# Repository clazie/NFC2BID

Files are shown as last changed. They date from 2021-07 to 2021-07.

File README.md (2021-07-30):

# NFC2BID

This project is based on a project from Rainer Kembügler ("onki") from  02. Dezember 2016 
(seen here: `https://onki.de/uebermich/bauberichte/289-bid2nfc-einbau-ins-ladegeraet <https://onki.de/uebermich/bauberichte/289-bid2nfc-einbau-ins-ladegeraet>`_ )

Information can also found here: `https://www.rc-network.de/threads/bid2nfc-als-nachr%C3%BCstl%C3%B6sung.587281/ <https://www.rc-network.de/threads/bid2nfc-als-nachr%C3%BCstl%C3%B6sung.587281/>`_

I collected all informations necessary to build it by my own and refactored the firmware for 
using it with PlatformIO.

# How to build PlatformIO based project

1. `Install PlatformIO Core <http://docs.platformio.org/page/core.html>`_
2. Download `development platform with examples <https://github.com/platformio/platform-atmelavr/archive/develop.zip>`_
3. Extract ZIP archive
4. Run these commands:

.. code-block:: bash

    # Change directory to example
    > cd platform-atmelavr/examples/arduino-blink

    # Build project
    > platformio run

    # Upload firmware
    > platformio run --target upload

    # Build specific environment
    > platformio run -e uno

    # Upload firmware for the specific environment
    > platformio run -e uno --target upload

    # Clean build files
    > platformio run --target clean

# Copyright PlatformIO
    Copyright 2014-present PlatformIO <contact@platformio.org>
    Licensed under the Apache License, Version 2.0 (the "License");
    you may not use this file except in compliance with the License.
    You may obtain a copy of the License at
       http://www.apache.org/licenses/LICENSE-2.0
    Unless required by applicable law or agreed to in writing, software
    distributed under the License is distributed on an "AS IS" BASIS,
    WITHOUT WARRANTIES OR CONDITIONS OF ANY KIND, either express or implied.
    See the License for the specific language governing permissions and
    limitations under the License.

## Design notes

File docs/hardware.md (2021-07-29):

Bei den RFID-RC522 muss man C8 und c8 durch 120pF Kondensatoren ersetzen um eine viel bessere Reichweite zu erreichen.
Wenn man dann unten den Tags noch eine 1,5mm GFK Scheibe legt gehen bei mir die 23mm ONMETALL problemlos.

## MFRC-522
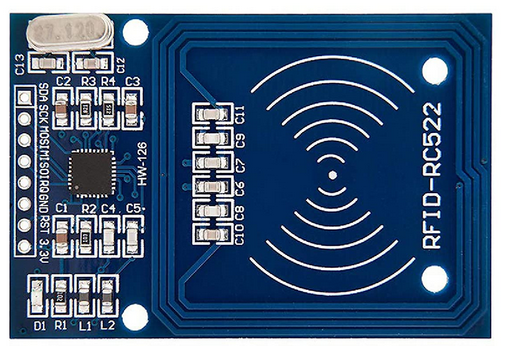
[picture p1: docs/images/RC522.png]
MFRC-522


Dieses RFID-Modul erlaubt das Auslesen und Beschreiben von RFID-Tags und ist sowohl für Einplatinen-Computer wie Raspberry Pi als auch für Einplatinen-Mikrocontroller wie Arduino einsetzbar.

• RFID-Modul mit integrierten NXP MFRC-522
• 13,56 MHz Frequenz
• Kommunikation über SPI
• basierend auf dem Mifare Protokoll
• erlaubt das Auslesen und Beschreiben von RFID-Tags

### RFID-Tags
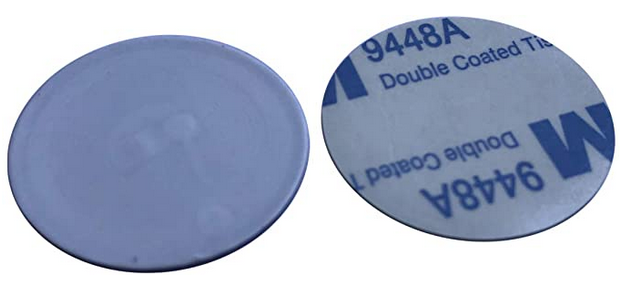
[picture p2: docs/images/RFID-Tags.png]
RFID-Tags


NFC Aufkleber RFID anti-metal auf Metall Tag Label MIFARE Classic® 1K 13,56MHz Dia 25mm

The tag is a Mifare transponder with 1 KB of memory which is divided into 16 sectors, each sector into 4 blocks and each block can store 2 bytes of data. Each sector has two keys (A/B) which can be assigned with rights for reading and writing memory blocks. The last block contains the keys and the rights (access conditions).

The sectors are numbered from 0 to 15 and the block number for every block (containing 2 bytes) is serially numbered from 0 to 63.

The Mifare classic has a proprietary “Crypto-1” algorithm which is not secure anymore since 2008. There are newer MIFARE DESFire EV1 and EV2 tags which are secure until today. But for some DIY projects the security is in my case not so important.

# Arduino Pro Mini 3,3V, 8MHz

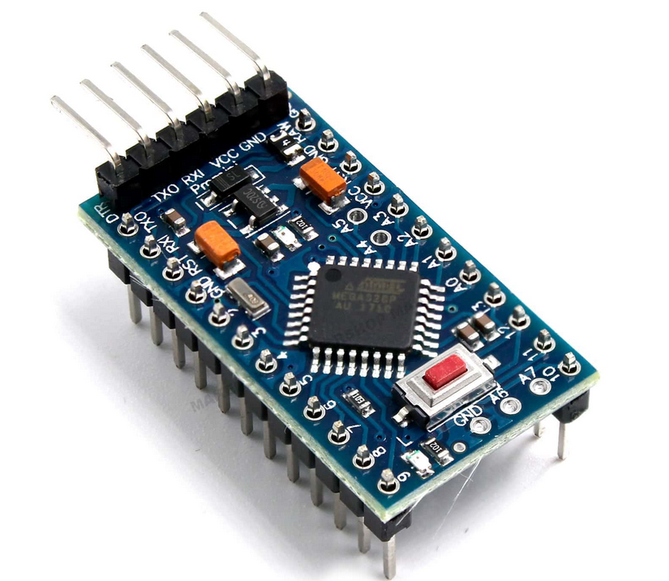
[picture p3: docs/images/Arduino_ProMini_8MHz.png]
Arduino Pro Mini 3,3V, 8MHz


# Verdrahtung
## RC522
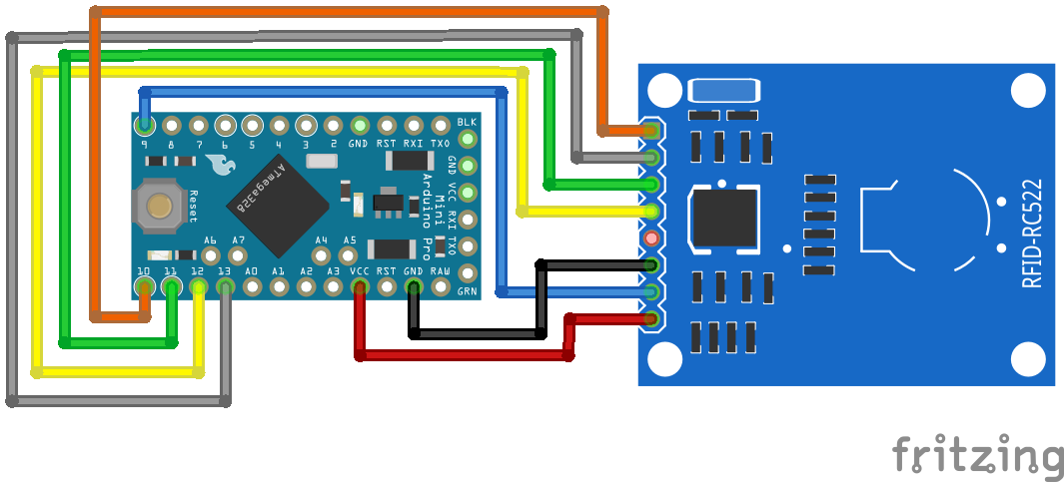
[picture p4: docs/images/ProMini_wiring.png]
Verdrahtung


| RC522 RFID Reader | Arduino Nano, Pro Mini 3.3V, Uno |
|---|---|
| SDA | 10 |
| SCK | 13 |
| MOSI | 11 |
| MISO | 12 |
| IRQ | not connected |
| GND | GND |
| RST | 9 |
| 3.3V | 3V3 |

## BID
| Signal | BID | ProMini  |
|---|---|---|
| GND | Black | GND |
| SCK | Green | A4 |
| SCL | White | A5 |
| VCC | Orange| not conn.|

## LED

| Signal | LED | ProMini |
|---|---|---|
| GND | K | GND |
| LED | A (330 Ohm) | A1 |

# Links
* [https://diyi0t.com/rfid-sensor-tutorial-for-arduino-and-esp8266/](https://diyi0t.com/rfid-sensor-tutorial-for-arduino-and-esp8266/)
* [https://onki.de/uebermich/bauberichte/288-bid2nfc-drahtlos-bid-chip-fuer-robbe-lader](https://onki.de/uebermich/bauberichte/288-bid2nfc-drahtlos-bid-chip-fuer-robbe-lader)
* [https://onki.de/uebermich/bauberichte/289-bid2nfc-einbau-ins-ladegeraet](https://onki.de/uebermich/bauberichte/289-bid2nfc-einbau-ins-ladegeraet)

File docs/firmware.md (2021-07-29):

## Links 
* [https://www.rc-network.de/threads/bid2nfc-als-nachr%C3%BCstl%C3%B6sung.587281/page-4](https://www.rc-network.de/threads/bid2nfc-als-nachr%C3%BCstl%C3%B6sung.587281/page-4)
* [https://www.rc-network.de/threads/bid2nfc-bid-kabellos-am-ladeger%C3%A4t-nutzen.11779777/](https://www.rc-network.de/threads/bid2nfc-bid-kabellos-am-ladeger%C3%A4t-nutzen.11779777/)
* [https://www.rc-thoughts.com/](https://www.rc-thoughts.com/)
* [https://apollo.open-resource.org/mission:log:2012:10:06:free-and-open-source-junsi-icharger-data-logger](https://apollo.open-resource.org/mission:log:2012:10:06:free-and-open-source-junsi-icharger-data-logger)
* [https://www.jetiforum.de/index.php/23-fremdprodukte/5653-arduino-library-fuer-jeti-ex-eigenbau-telemetrie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](https://www.jetiforum.de/index.php/23-fremdprodukte/5653-arduino-library-fuer-jeti-ex-eigenbau-telemetrie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)
* [https://sourceforge.net/projects/jetiexsensorcpplib/](https://sourceforge.net/projects/jetiexsensorcpplib/)
* [https://github.com/openXsensor/openXsensor/wiki](https://github.com/openXsensor/openXsensor/wiki)
* [https://maskaravivek.medium.com/understanding-the-format-of-ndef-messages-part-1-44ec179a5f45](https://maskaravivek.medium.com/understanding-the-format-of-ndef-messages-part-1-44ec179a5f45)
*  [https://github.com/Sepp62/JetiExBus](https://github.com/Sepp62/JetiExBus)

# Ausgaben auf der seriellen

```
V1.0.0
Scan a MIFARE Classic card
Chip gefunden!     
Lese Seriennummer aus :block was read
EB74496EB88402C778ABB477F81D
Start lesenblock was read
block was read
block was read
block was read
block was read
block was read
block was read
block was read
block was read
block was read
block was read
block was read
block was read
block was read
block was read
block was read
ende lesen    
Print BID Data
00: 02 97 00 04 00 04 00 00 00 00 00 00 00 00 00 00
10: 00 00 00 00 00 00 00 00 00 00 00 00 00 00 00 00
20: 00 00 00 00 00 00 00 00 00 00 00 00 00 00 00 00
30: 00 00 00 00 00 00 00 00 00 00 00 00 00 00 00 00
40: 0f 04 10 02 03 13 88 27 10 13 88 0b b8 00 37 00
50: 00 00 00 00 00 00 00 00 00 00 00 00 00 00 00 00
60: 00 00 00 00 00 00 00 00 00 00 00 00 00 00 00 00
70: 00 00 00 00 00 00 00 00 00 00 00 00 00 00 00 00
80: 02 97 00 04 00 04 00 00 00 00 00 00 00 00 00 00
90: 00 00 00 00 00 00 00 00 00 00 00 00 00 00 00 00
a0: 00 00 00 00 00 00 00 00 00 00 00 00 00 00 00 00
b0: 00 00 00 00 00 00 00 00 00 00 00 00 00 00 00 00
c0: 0f 04 10 02 03 13 88 27 10 13 88 0b b8 00 37 00
d0: 00 00 00 00 00 00 00 00 00 00 00 00 00 00 00 00
e0: 00 00 00 00 00 00 00 00 00 00 00 00 00 00 00 00
f0: 00 00 00 00 00 00 00 00 00 00 00 00 00 00 00 00
Checksum:       663
act_charge:     4
max_charged:    4
chg_cycles:     0
year:           15
month:          4
day:            16
acctyp:         2
cells:          3
capacity:       5000
chg_current:    10000
dischg_current: 5000
dischg_limit:   3000
d_peak:         0
cut_temp:       55
unknown:        0
unknown_8[0]:   0
unknown_8[1]:   0
unknown_8[2]:   0
unknown_8[3]:   0
unknown_8[4]:   0
unknown_8[5]:   0
unknown_8[6]:   0
unknown_8[7]:   0
read errors:
0
```

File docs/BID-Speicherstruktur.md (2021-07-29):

## Struktur

```c
#pragma pack(push, 1)
typedef struct {
  endian16  checksum;         // [0..1]  Checksum, sum up bytes from 2..127
  endian16  act_charge;       // [2..3]
  endian16  max_charged;      // [4..5]
  endian16  chg_cycles;       // [6..7]
  uint8_t   unknown_8[63-7];  // [8..63]
  uint8_t   year;             // [64]
  uint8_t   month;            // [65]
  uint8_t   day;              // [66]
  uint8_t   acctyp;           // [67]
  uint8_t   cells;            // [68]
  endian16  capacity;         // [69..70]
  endian16  chg_current;      // [71..72]
  endian16  dischg_current;   // [73..74]
  endian16  dischg_limit;     // [75..76] discharge limit in mv/Cell
  uint8_t   d_peak;           // [77] delta peak value
  uint8_t   cut_temp;         // [78] cut off temperature
  uint8_t   unknown;
  uint8_t   unknown75[128-80];
}tBID_data;
#pragma pack(pop)
```
Infos gibt|s hier[https://www.rc-network.de/threads/bid-bzw-ams-mit-pc-auslesen486956/](https://www.rc-network.de/threads/bid-bzw-ams-mit-pc-auslesen.486956/) und hier:[https://rchelifan.org/viewtopic.php?f=63&t=59994&hilit=BID+Chip](https://rchelifan.org/viewtopic.php?f=63&t=59994&hilit=BID+Chip).

* Checksumme
* Akkutyp
* Zellenzahl
* Akkukapazität
* Ladestrom
* Entladestrom
* Akkudatum (Tag, Monat, Jahr)
* Anzahl Zyklen
* geladene Kapazität (letzter Ladevorgang)
* entladene Kapazität (letzter Entladevorgang)
* geladene Kapazität (Maximalwert)
* entladene Kapazität (Maximalwert)

Zur Speicherorganisation: Es stehen insgesamt 256 Byte zur Verfügung (8 x 256 Byte = 2 kBit)
Die Daten werden vom Byte 0 bis 127 geschrieben und anschließend ein zweites Mal von Byte 128 bis 255,
also eine 1:1 Spiegelung. Für die obengenannten Daten werden derzeit 23 Bytes genutzt (gespiegelt also 46 Byte von 256 zur Verfügung stehenden Bytes).

+----------------+
|J1     +-+ C1   |
|--+    +-+      |
|  |1   8 7 6 5  |
|  |2   +-----+  |
|  |3   ) IC1 |  |
|  |4   +-----+  |
|--+    1 2 3 4  |
+----------------+

J1:
1 ... or --> VCC --> Arduino 5V
2 ... ws --> SCL --> Arduino Pin 5
3 ... gn --> SDA --> Arduino Pin 4
4 ... sw --> GND --> Arduino GND

IC1: A21SC (=> 24C02 ?)
1 ... E0  --> GND
2 ... E1  --> GND
3 ... E2  --> GND
4 ... GND --> J1-4
5 ... SDA --> J1-3
6 ... SCL --> J1-2
7 ... /WC --> GND  --> C1-1
8 ... VCC --> J1-1 --> C1-2

```c++
#include <Wire.h>

#define BID_ADDRESS (0xA << 3 | 0x0)

int bid_year, bid_month, bid_day;
int bid_cells, bid_acctyp, bid_cap_h, bid_cap_l, bid_chcurr_h, bid_chcurr_l, bid_dchcurr_h, bid_dchcurr_l;
int bid_actc_h, bid_actc_l, bid_actdc_h, bid_actdc_l, bid_maxc_h, bid_maxc_l;
int bid_chcnt_h, bid_chcnt_l;

// EEPROM Routine from http://www.arduino.cc/playground/Code/I2CEEPROM
// adopted to read EEPROMS with 1 Byte address
byte i2c_eeprom_read_byte( int deviceaddress, byte eeaddress ) {
  byte rdata = 0xFF;
  Wire.beginTransmission(deviceaddress);
//  Wire.send((int)(eeaddress >> 8)); // MSB
//  Wire.send((int)(eeaddress & 0xFF)); // LSB
  Wire.send((int)(eeaddress)); 
  Wire.endTransmission();
  Wire.requestFrom(deviceaddress,1);
  if (Wire.available()) rdata = Wire.receive();
  return rdata;
}

void setup() {
  // ...
  Wire.begin();   // start Wire library as I2C-Bus Master
  Serial.begin(9600); // 
  
    int i;
    byte bid_data;
    
    Serial.print("BID-Adresse: ");
    Serial.println(BID_ADDRESS, HEX);    
    
  Serial.println("Start EEPROM_READ");
for (i = 0; i <= 255; i++){
    Serial.print(i, DEC);
    Serial.print(": ");
    bid_data = i2c_eeprom_read_byte( BID_ADDRESS, i );
    Serial.println(bid_data, HEX); 
      switch (i) {
    case 2:
      //Actual Chaged Capacity (mAh) High Byte
      bid_actc_h = bid_data;
      break;
    case 3:
      //Actual Chaged Capacity (mAh) Low Byte
      bid_actc_l = bid_data;
      break;
    case 4:
      //Maximum Chaged Capacity (mAh) High Byte
      bid_maxc_h = bid_data;
      break;
    case 5:
      //Maxiimum Chaged Capacity (mAh) Low Byte
      bid_maxc_l = bid_data;
      break;
    case 6:
      //Charging Cycles High Byte
      bid_chcnt_h = bid_data;
      break;
    case 7:
      //Charging Cycles Low Byte
      bid_chcnt_l = bid_data;
      break;

    case 64:
      //Year
      bid_year = bid_data;
      break;
    case 65:
      //Month
      bid_month = bid_data;
      break;
    case 66:
      //Day
      bid_day = bid_data;
      break;
    case 67:
      //Accu Type
      bid_acctyp = bid_data;
      break;
    case 68:
      //Cells
      bid_cells = bid_data;
      break;
    case 69:
      //Capacaity(mAh) High Byte
      bid_cap_h = bid_data;
      break;
    case 70:
      //Capacaity(mAh) Low Byte
      bid_cap_l = bid_data;
      break;
    case 71:
      //Charg. Current(mA) High Byte
      bid_chcurr_h = bid_data;
      break;
    case 72:
      //Charg. Current(mA) Low Byte
      bid_chcurr_l = bid_data;
      break;
    case 73:
      //Discharg. Current(mA) High Byte
      bid_dchcurr_h = bid_data;
      break;
    case 74:
      //Discharg. Current(mA) Low Byte
      bid_dchcurr_l = bid_data;
      break;
  }

    delay(5);
}
  Serial.println("End EEPROM_READ");

Serial.println("BID Daten:");
Serial.print("Datum: ");
Serial.print(bid_day);
Serial.print(".");
Serial.print(bid_month);
Serial.print(".");
Serial.print(2000 + bid_year);
Serial.println("");

Serial.print("Akku-Typ: ");
      switch (bid_acctyp) {
        case 0:
          Serial.print("NiCd");
          break;
        case 1:
          Serial.print("NiMH");
          break;
        case 2:
          Serial.print("LiPo");
          break;
        default:
          Serial.print(bid_acctyp);
          Serial.print("?");
          break;
      }
Serial.println("");

Serial.print("Zellenzahl: ");
Serial.print(bid_cells);
Serial.print(" -> ");
      switch (bid_acctyp) {
        case 0:
          Serial.print(1.2 * bid_cells);
          break;
        case 1:
          Serial.print(1.2 * bid_cells);
          break;
        case 2:
          Serial.print(3.7 * bid_cells);
          break;
      }
Serial.print(" V");
Serial.println("");

Serial.print("Kapazitaet: ");
Serial.print(bid_cap_h * 256 + bid_cap_l);
Serial.print(" mAh");
Serial.println("");

Serial.print("Ladestrom: ");
Serial.print(bid_chcurr_h * 256 + bid_chcurr_l);
Serial.print(" mA");
Serial.println("");

Serial.print("Entladestrom: ");
Serial.print(bid_dchcurr_h * 256 + bid_dchcurr_l);
Serial.print(" mA");
Serial.println("");

Serial.print("akt. Lad.: ");
Serial.print(bid_actc_h * 256 + bid_actc_l);
Serial.print(" mAh");
Serial.println("");

Serial.print("max. Lad.: ");
Serial.print(bid_maxc_h * 256 + bid_maxc_l);
Serial.print(" mAh");
Serial.println("");

Serial.print("Ladezyklen: ");
Serial.print(bid_chcnt_h * 256 + bid_chcnt_l);
Serial.println("");

  // ...
}

void loop() {
  // ...
  // ...
}

```

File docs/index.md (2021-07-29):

# NFC2BID

Diese Dokumentation wurde mit MkDocs erstellt. Bitte bei Änderungen nicht die Html-Seiten auf dem Webserver ändern, sondern die **"*.md"** Datei im Unterverzeichnis **"docs"** der Quelldateien ändern.

Die Quelldateien befinden sich im Verzeichnis **docs** des Repositorys
## Serve
Mit dem Kommando 
```sh
mkdocs serve
```
wird ein Webserver gestartet und die erzeugten Doc-Html Dateien können mit dem Webbrowser unter der Adresse [`http://localhost:8000/`](http://localhost:8000/) aufgerufen werden. Jede Änderung wird im Webbrowser direkt sichtbar. Mit `Ctrl-C` wird der Webserver beendet.

## Build
Mit dem Kommando 
```sh
mkdocs build
```
werden die Html-Dateien erzeugt und in das Webserver Verzeichnis `\\raspidbsrv\web\html\doku\nfc2bid` kopiert und kann dann im Webbrowser unter der Adresse [`https://192.168.15.107/doku/nfc2bid/`](https://192.168.15.107/doku/nfc2bid/) aufgerufen werden.

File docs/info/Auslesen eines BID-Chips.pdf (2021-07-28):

Auslesen eines BID-Chips mit Arduino. Verwendetes EEPROM: 24LC02 (256x8 Bit)

BID-Adresse (DEC): 80

Start EEPROM_READ

Byte: Inhalt

(DEC) (HEX)

0: | 2A
1: | 4
2: | 0
3: | 0
4: | 0
5: | 0
6: | 0
7: | 0
8: | 6
9: | 28
10: | 6
11: | 28
12: | 0
13: | 0
14: | 0
15: | 0
16: | 0
17: | 0
18: | 0
19: | 0
20: | 0
21: | 0

22: | 0
23: | 0
24: | 0
25: | 0
26: | 0
27: | 0
28: | 0
29: | 0
30: | 0
31: | 0
32: | 0
33: | 0
34: | 0
35: | 0
36: | 0
37: | 0
38: | 0
39: | 0
40: | 0
41: | 0
42: | 0
43: | 0
44: | 0
45: | 0
46: | 0
47: | 0
48: | 0
49: | 0

50: | 0
51: | 0
52: | 0
53: | 0
54: | 0
55: | 0
56: | 0
57: | 0
58: | 0
59: | 0
60: | 0
61: | 0
62: | 0
63: | 0
64: | 11
65: | 3
66: | 3
67: | 2
68: | 6
69: | 13
70: | 88
71: | 1F
72: | A4
73: | 13
74: | 88
75: | C
76: | 80
77: | 4

78: | 0
79: | 0
80: | 0
81: | 0
82: | 0
83: | 0
84: | 0
85: | 0
86: | 0
87: | 0
88: | 0
89: | 0
90: | 0
91: | 0
92: | 0
93: | 0
94: | 0
95: | 0
96: | 0
97: | 0
98: | 0
99: | 0
100: | 0
101: | 0
102: | 0
103: | 0
104: | 0
105: | 0

106: | 0
107: | 0
108: | 0
109: | 0
110: | 0
111: | 0
112: | 0
113: | 0
114: | 0
115: | 0
116: | 0
117: | 0
118: | 0
119: | 0
120: | 0
121: | 0
122: | 0
123: | 0
124: | 0
125: | 0
126: | 0
127: | 0
128: | 3
129: | 4
130: | 0
131: | 0
132: | 0
133: | 0

134: | 0
135: | 0
136: | 6
137: | 28
138: | 6
139: | 28
140: | 0
141: | 0
142: | 0
143: | 0
144: | 0
145: | 0
146: | 0
147: | 0
148: | 0
149: | 0
150: | 0
151: | 0
152: | 0
153: | 0
154: | 0
155: | 0
156: | 0
157: | 0
158: | 0
159: | 0
160: | 0
161: | 0

162: | 0
163: | 0
164: | 0
165: | 0
166: | 0
167: | 0
168: | 0
169: | 0
170: | 0
171: | 0
172: | 0
173: | 0
174: | 0
175: | 0
176: | 0
177: | 0
178: | 0
179: | 0
180: | 0
181: | 0
182: | 0
183: | 0
184: | 0
185: | 0
186: | 0
187: | 0
188: | 0
189: | 0

190: | 0
191: | 0
192: | 11
193: | 3
194: | 3
195: | 2
196: | 6
197: | 13
198: | 88
199: | 1F
200: | A4
201: | 13
202: | 88
203: | C
204: | 80
205: | 4
206: | 0
207: | 0
208: | 0
209: | 0
210: | 0
211: | 0
212: | 0
213: | 0
214: | 0
215: | 0
216: | 0
217: | 0

218: | 0
219: | 0
220: | 0
221: | 0
222: | 0
223: | 0
224: | 0
225: | 0
226: | 0
227: | 0
228: | 0
229: | 0
230: | 0
231: | 0
232: | 0
233: | 0
234: | 0
235: | 0
236: | 0
237: | 0
238: | 0
239: | 0
240: | 0
241: | 0
242: | 0
243: | 0
244: | 0
245: | 0

246: | 0
247: | 0
248: | 0
249: | 0
250: | 0
251: | 0
252: | 0
253: | 0
254: | 0
255: | 0

End EEPROM_READ

BID Daten:

Datum: 3.3.2017

Akku-Typ: LiPo

Zellenzahl: 6 -> 22.20 V

Kapazitaet: 5000 mAh

Ladestrom: 8100 mA

Entladestrom: 5000 mA

akt. Lad.: 0 mAh

max. Lad.: 0 mAh

Ladezyklen: 0

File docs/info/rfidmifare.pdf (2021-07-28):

## Using a MFRC522 reader to read and write MIFARE RFID cards

on ARDUINO through the MFRC522 library BY COOQROBOT.
Mario Capurso (m.capurso@libero.it)

MIFARE is the NXP Semiconductors-owned trademark of a series of chips widely
used in contactless smart cards and proximity cards. According to the producers, billions of smart card chips and many millions of reader modules have been sold. [1]

The technology is owned by NXP Semiconductors (spin off from Philips Electronics in 2006) with headquarters in Eindhoven, Netherlands, and main business sites in Nijmegen, Netherlands, and Hamburg, Germany.

The MIFARE name covers proprietary technologies based upon various levels of the ISO/IEC 14443 Type A 13.56 MHz contactless smart card standard.
The MIFARE name (derived from the term MIkron FARE Collection System) covers
seven different kinds of contactless cards.

MIFARE Classic employs a proprietary protocol compliant to parts (but not all) of ISO/IEC 14443-3 Type A, with an NXP proprietary security protocol for authentication and ciphering.

The MIFARE Classic card is fundamentally just a memory storage device, where the memory is divided into segments and blocks with simple security mechanisms for access control. They are ASIC-based and have limited computational power. Thanks
to their reliability and low cost, those cards are widely used for electronic wallet, access control, corporate ID cards, transportation or stadium ticketing.

The MIFARE Classic 1K offers 1024 bytes of data storage, split into 16 sectors; each sector is protected by two different keys, called A and B. Each key can be programmed to allow operations such as reading, writing, increasing valueblocks, etc. MIFARE Classic 4K offers 4096 bytes split into forty sectors, of which 32 are same size as in the 1K with eight more that are quadruple size sectors. MIFARE Classic mini offers 320 bytes split into five sectors.

For each of these card types, 16 bytes per sector are reserved for the keys and access conditions and can not normally be used for user data. Also, the very first 16 bytes contain the serial number of the card and certain other manufacturer data and are read only. That brings the net storage capacity of these cards down to 752 bytes for MIFARE Classic 1k, 3440 bytes for MIFARE Classic 4k, and 224 bytes for Mini. It uses an NXP proprietary security protocol (Crypto-1) for authentication and ciphering.

The encryption used by the MIFARE Classic card uses a 48 bit key. [18]
A presentation by Henryk Plötz and Karsten Nohl[19] at the Chaos Communication Congress in December 2007 described a partial reverse-engineering of the algorithm used in the MIFARE Classic chip. Abstract and slides[20] are available online. A paper that describes the process of reverse engineering this chip was published at the August 2008 USENIX security conference.[21] (https://www.usenix.org/legacy/events/sec08/tech/full_papers/nohl/nohl.pdf)

In March 2008 the Digital Security[22] research group of the Radboud University Nijmegen made public that they performed a complete reverse-engineering and
were able to clone and manipulate the contents of an OV-Chipkaart which is a MIFARE Classic card.[23] (http://www.cs.ru.nl/~flaviog/publications/Talk.Mifare.pdf) For demonstration they used the Proxmark device, a 125 kHz / 13.56 MHz research instrument.[24] The schematics and software are released under the free GNU General Public License by Jonathan Westhues in 2007. They demonstrate it is even possible to perform card-only attacks using just an ordinary stock-commercial NFC reader in combination with the libnfc library.

In April 2009 new and better card-only attack on MIFARE Classic has been
found. It was first announced at the Rump session of Eurocrypt 2009.[35] This attack was presented at SECRYPT 2009.[36] The full description of this latest and fastest attack to date can also be found in the IACR preprint archive.[37] The new attack improves by a factor of more than 10 all previous card-only attacks on MIFARE Classic, has instant running time, and it does not require a costly precomputation.

The new attack allows to recover the secret key of any sector of MIFARE Classic card via wireless interaction, within about 300 queries to the card. It can then be combined with the nested authentication attack in the Nijmegen Oakland paper to recover subsequent keys almost instantly. Both attacks combined and with the right hardware equipment such as Proxmark3, one should be able to clone any MIFARE Classic card in not more than 10 seconds. This is much faster than previously thought.

The MFRC522 is a highly integrated reader/writer IC for contactless communication at 13.56 MHz. The MFRC522 reader supports ISO/IEC 14443 A/MIFARE mode.
The MFRC522’s internal transmitter is able to drive a reader/writer antenna designed to communicate with ISO/IEC 14443 A/MIFARE cards and transponders without additional active circuitry. The receiver module provides a robust and efficient implementation for demodulating and decoding signals from ISO/IEC 14443 A/MIFARE compatible cards and transponders. The digital module manages the complete ISO/IEC 14443 A framing and error detection (parity and CRC) functionality.

The MFRC522 supports all variants of the MIFARE Mini, MIFARE 1K, MIFARE 4K, MIFARE Ultralight, MIFARE DESFire EV1 and MIFARE Plus RF identification protocols. To aid readability throughout this data sheet, the MIFARE Mini,

MIFARE 1K, MIFARE 4K, MIFARE Ultralight, MIFARE DESFire EV1 and MIFARE Plus products and protocols have the generic name MIFARE.

The following host interfaces are provided:

- Serial Peripheral Interface (SPI)
- Serial UART (similar to RS232 with voltage levels dependant on pin voltage supply)
- I2C-bus interface


Answer to Request :

With the Answer to Request sequence the MIFARE® RWD (Read Write Device) requests all MIFARE® cards in the antenna field. When a card is in the operating range of a RWD, the RWD continues communication with the appropriate protocol.

Anticollision loop
In the Anticollision loop the serial number of the card is read. If there are several cards in the operating range of a RWD they can be distinguished by their different serial numbers and one can be selected (Select card) for further transactions. The unselected cards return to the standby mode and wait for a new Answer to Request and Anticollision loop.

Select Card
With the Select Card command the RWD selects one individual card for further authentication and memory related operations. The card returns the Answer to Select (ATS) code, which determines the individual type of the selected card.

Access Specification
After identification and selection of one card the RWD specifies the memory location of the following access.

Three Pass Authentication
The appropriate access key for the previously specified access is used for 3 Pass Authentication. Any communication after authentication is automatically encrypted at the sender and decrypted by the receiver.

Read/Write

After authentication any of the following operations may be performed:

READ | reads one block
WRITE | writes one block
DECREMENT | decrements the contents of one block and stores the result
| in the data-register
INCREMENT | increments the contents of one block and stores the result
| in the data-register
TRANSFER | writes the contents of the data-register to one block
RESTORE | stores the contents of one block in the data-register

The MF1ICS50 IC of a Mifare Classic has integrated a 8192 Bit EEPROM which is split into 16 sectors with 4 blocks. One block consists of 16 bytes (1 Byte = 8 Bit).


Manufacturer Code (Block 0 of Sector 0)

The first block of the memory is reserved for manufacturer data like 32 bit serial number. This is a read only block. In many documents it is named "Block 0".

Data Block (Block 0 to 3 except "Block 0")

Access conditions for the Data Blocks are defined in the Sector Trailers. According to these conditions data can be read, written, incremented, decremented, transferred or restored either with Key A, Key B or never.

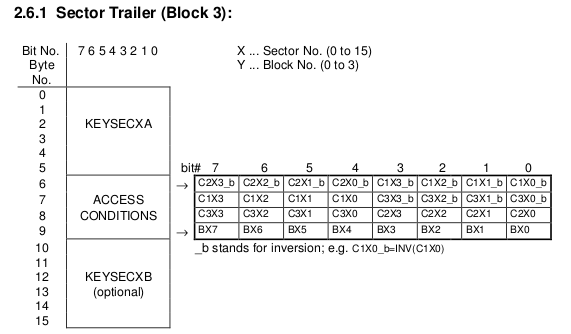
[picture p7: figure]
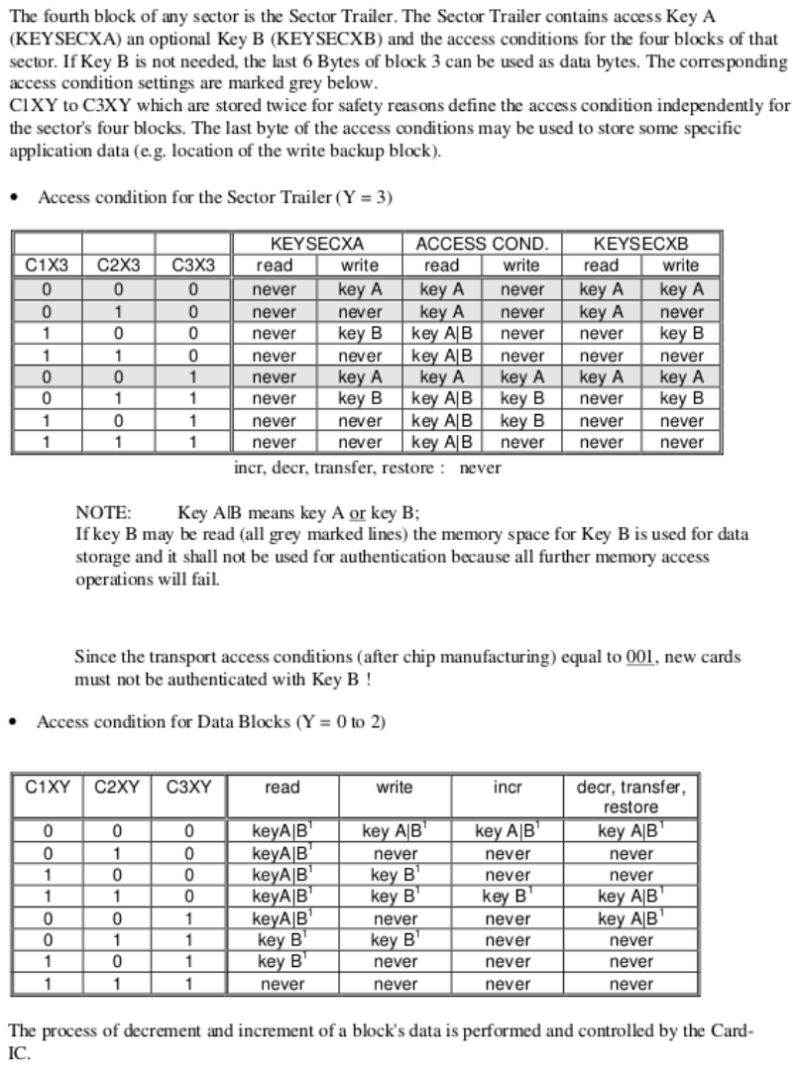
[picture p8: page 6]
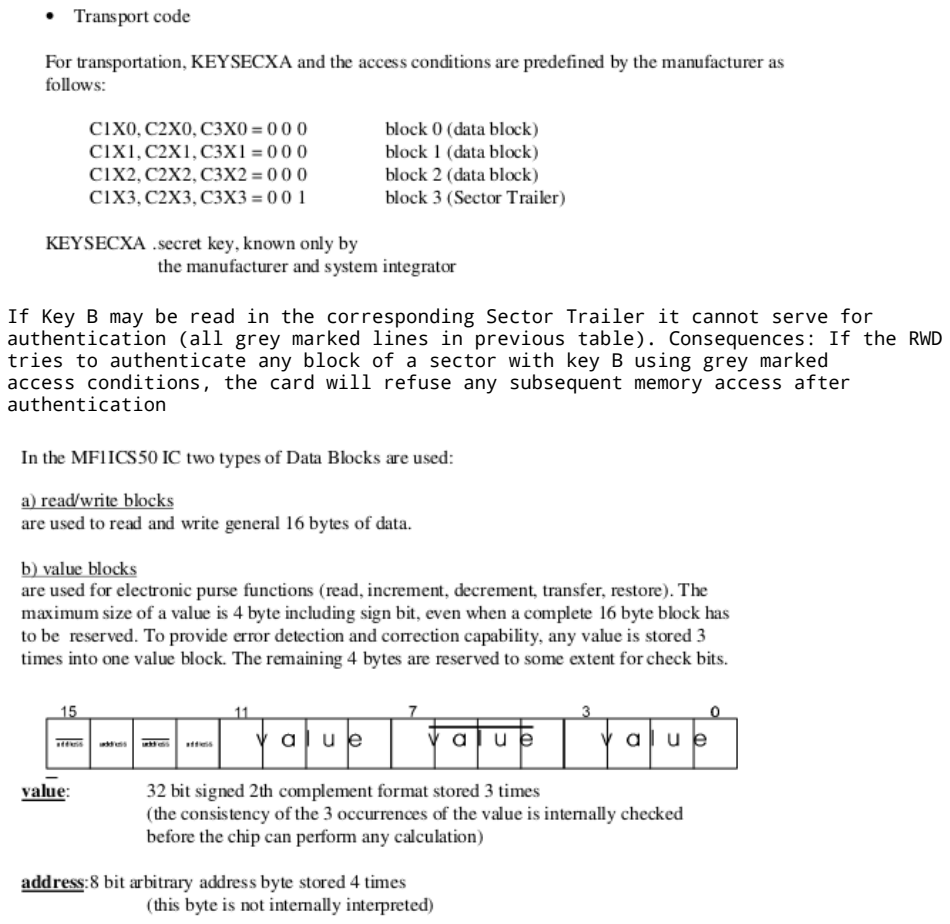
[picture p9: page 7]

If Key B may be read in the corresponding Sector Trailer it cannot serve for authentication (all grey marked lines in previous table). Consequences: If the RWD tries to authenticate any block of a sector with key B using grey marked
access conditions, the card will refuse any subsequent memory access after authentication

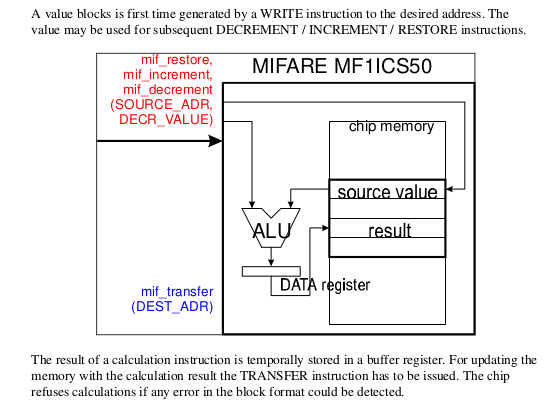
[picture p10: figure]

The described memory organization makes it possible to appoint different sectors to different applications and to prevent data corruption by using application specific secret keys. Keys can only be altered by a RWD which has stored the actual Key A or Key B if this is allowed according to access conditions. Otherwise the actual key cannot be changed anymore.

Before the execution of a command the correct format of the Access Conditions is checked by the Card-IC. Thus, when programming the Sector Trailer the card needs to be fixed within the operating range of a RWD's antenna to prevent interruption of the write operation because any unsuccessful write operation may lead to blocking the whole sector.

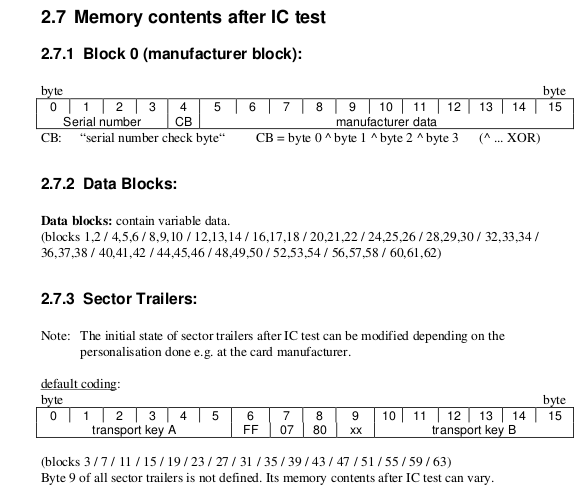
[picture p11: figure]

## MFRC522.h – A Library to use ARDUINO RFID MODULE KIT 13.56

MHZ BY COOQROBOT.

There are three hardware components involved:

1) The micro controller: An Arduino
2) The PCD (Proximity Coupling Device): NXP MFRC522 Contactless Reader IC
3) The PICC (short for Proximity Integrated Circuit Card): A card or tag using the ISO 14443A interface, eg Mifare or NTAG203.

MIFARE Classic 1K (MF1S503x):

Has 16 sectors * 4 blocks/sector * 16 bytes/block = 1024 bytes. The blocks are numbered 0-63.

Block 3 in each sector is the Sector Trailer.
* | Bytes 0-5: | Key A
* | Bytes 6-8: | Access Bits
* | Bytes 9: | User data
* | Bytes 10-15: Key B (or user data)

Block 0 is read only manufacturer data.

To access a block, an authentication using a key from the block's sector must be performed first.

Example: To read from block 10, first authenticate using a key from sector 3 (blocks 8-11).

All keys are set to FFFFFFFFFFFFh at chip delivery.

Warning: Please read section 8.7 "Memory Access". It includes this text: if the PICC detects a format violation the whole sector is irreversibly blocked.

To use a block in "value block" mode (for Increment/Decrement operations) you need to change the sector trailer. Use PICC_SetAccessBits() to calculate the bit patterns.

Commands sent to the PICC.

The commands used by the PCD to manage communication with several PICCs (ISO 14443-3, Type A, section 6.4)

PICC_CMD_REQA = 0x26,
REQuest command, Type A. Invites PICCs in state IDLE to go to READY and prepare for anticollision or selection. 7 bit frame.
PICC_CMD_WUPA = 0x52,
Wake-UP command, Type A. Invites PICCs in state IDLE and HALT to go to READY(*) and prepare for anticollision or selection. 7 bit frame.
PICC_CMD_CT = 0x88,
Cascade Tag. Not really a command, but used during anti collision. PICC_CMD_SEL_CL1 = 0x93,
Anti collision/Select, Cascade Level 1
PICC_CMD_SEL_CL2 = 0x95,
Anti collision/Select, Cascade Level 2 PICC_CMD_SEL_CL3 = 0x97,
Anti collision/Select, Cascade Level 3
PICC_CMD_HLTA = 0x50,
HaLT command, Type A. Instructs an ACTIVE PICC to go to state HALT.

The commands used for MIFARE Classic
Use PCD_MFAuthent to authenticate access to a sector, then use these commands to read/write/modify the blocks on the sector.
The read/write commands can also be used for MIFARE Ultralight.

PICC_CMD_MF_AUTH_KEY_A = 0x60,
Perform authentication with Key A
PICC_CMD_MF_AUTH_KEY_B = 0x61,
Perform authentication with Key B
PICC_CMD_MF_READ | = 0x30,
Reads one 16 byte block from the authenticated sector of the PICC. Also used for MIFARE Ultralight.
PICC_CMD_MF_WRITE | = 0xA0,
Writes one 16 byte block to the authenticated sector of the PICC. Called "COMPATIBILITY WRITE" for MIFARE Ultralight.
PICC_CMD_MF_DECREMENT = 0xC0,
Decrements the contents of a block and stores the result in the internal data register.
PICC_CMD_MF_INCREMENT = 0xC1,
Increments the contents of a block and stores the result in the internal data register.
PICC_CMD_MF_RESTORE | = 0xC2,
Reads the contents of a block into the internal data register. PICC_CMD_MF_TRANSFER = 0xB0,
Writes the contents of the internal data register to a block.

List of the functions in the library

Functions for setting up the Arduino

MFRC522(byte chipSelectPin, byte resetPowerDownPin);
void setSPIConfig();

Basic interface functions for communicating with the MFRC522

void PCD_WriteRegister(byte reg, byte value);
void PCD_WriteRegister(byte reg, byte count, byte *values);
byte PCD_ReadRegister(byte reg);
void PCD_ReadRegister(byte reg, byte count, byte *values, byte rxAlign = 0); void setBitMask(unsigned char reg, unsigned char mask);
void PCD_SetRegisterBitMask(byte reg, byte mask);
void PCD_ClearRegisterBitMask(byte reg, byte mask);
byte PCD_CalculateCRC(byte *data, byte length, byte *result);

Functions for manipulating the MFRC522

void PCD_Init();
void PCD_Reset();
void PCD_AntennaOn();

Functions for communicating with PICCs

byte PCD_TransceiveData(byte *sendData, byte sendLen, byte *backData, byte *backLen, byte *validBits = NULL, byte rxAlign = 0, bool checkCRC = false);

byte PCD_CommunicateWithPICC(byte command, byte waitIRq, byte *sendData, byte sendLen, byte *backData = NULL, byte *backLen = NULL, byte *validBits = NULL, byte rxAlign = 0, bool checkCRC = false);

byte PICC_RequestA(byte *bufferATQA, byte *bufferSize);
byte PICC_WakeupA(byte *bufferATQA, byte *bufferSize);
byte PICC_REQA_or_WUPA( byte command, byte *bufferATQA, byte *bufferSize); byte PICC_Select(Uid *uid, byte validBits = 0);
byte PICC_HaltA();

Functions for communicating with MIFARE PICCs

byte PCD_Authenticate(byte command, byte blockAddr, MIFARE_Key *key, Uid *uid); void PCD_StopCrypto1();
byte MIFARE_Read(byte blockAddr, byte *buffer, byte *bufferSize);
byte MIFARE_Write(byte blockAddr, byte *buffer, byte bufferSize);
byte MIFARE_Decrement(byte blockAddr, long delta);
byte MIFARE_Increment(byte blockAddr, long delta);
byte MIFARE_Restore(byte blockAddr);
byte MIFARE_Transfer(byte blockAddr);
byte MIFARE_Ultralight_Write(byte page, byte *buffer, byte bufferSize);

Support functions

byte PCD_MIFARE_Transceive( byte *sendData, byte sendLen, bool acceptTimeout = false);
const char *GetStatusCodeName(byte code);
byte PICC_GetType(byte sak);
const char *PICC_GetTypeName(byte type);
void PICC_DumpToSerial(Uid *uid);
void PICC_DumpMifareClassicToSerial(Uid *uid, byte piccType, MIFARE_Key *key);
void PICC_DumpMifareClassicSectorToSerial(Uid *uid, MIFARE_Key *key, byte sector); void PICC_DumpMifareUltralightToSerial();
void MIFARE_SetAccessBits(byte *accessBitBuffer, byte g0, byte g1, byte g2, byte g3);

Convenience functions - does not add extra functionality

bool PICC_IsNewCardPresent();
bool PICC_ReadCardSerial();

Detailed documentation – enum and structures

PICC types we can detect. Remember to update PICC_GetTypeName() if you add more.

enum PICC_Type

Return codes from the functions in this class. Remember to update GetStatusCodeName() if you add more.

enum StatusCode

A struct used for passing the UID of a PICC.

typedef struct {
byte | size; | Number of bytes in the UID. 4, 7 or 10.
byte | uidByte[10];
byte | sak; | The SAK (Select acknowledge) byte returned
| | from the PICC after successful selection.
} Uid

A struct used for passing a MIFARE Crypto1 key

typedef struct {
byte | keyByte[MF_KEY_SIZE];
} MIFARE_Key;

Example:
// Prepare key - all keys are set to FFFFFFFFFFFFh at chip delivery from the factory. MFRC522::MIFARE_Key key;
for (byte i = 0; i < 6; i++) key.keyByte[i] = 0xFF;

Member variables

Uid uid; | Used by PICC_ReadCardSerial().

Detailed documentation – functions

+Create object instance
MFRC522(
byte chipSelectPin, Arduino pin used for SPI chip select byte resetPowerDownPin Arduino pin used for SPI reset
);
Example:
#include <SPI.h>

#include <MFRC522.h>

#define SS_PIN 10 //Arduino Uno

#define RST_PIN 9

MFRC522 mfrc522(SS_PIN, RST_PIN); | // Create MFRC522 instance.

+Initializes the MFRC522 chip.
void MFRC522::PCD_Init()
Example:
void setup() {
Serial.begin(9600); | // Init serial communications with PC
SPI.begin(); | // Init SPI bus
mfrc522.PCD_Init(); | // Init MFRC522 card
}

+Set SPI bus to work with MFRC522 chip.

Please call this function if you have changed the SPI config since the MFRC522 constructor was run.

void MFRC522::setSPIConfig()

+Performs a soft reset on the MFRC522 chip and waits for it to be ready again. void MFRC522::PCD_Reset()

+Turns the antenna on by enabling pins TX1 and TX2.
After a reset these pins are disabled.
void MFRC522::PCD_AntennaOn()

+Transmits a REQuest command, Type A. Invites PICCs in state IDLE to go to READY and prepare for anticollision or selection. 7 bit frame.
Beware: When two PICCs are in the field at the same time I often get STATUS_TIMEOUT -probably due do bad antenna design.
return STATUS_OK on success, STATUS_??? otherwise.
byte MFRC522::PICC_RequestA(
byte *bufferATQA, The buffer to store the ATQA (Answer to request) in
byte *bufferSize Buffer size, at least two bytes. Also number of bytes returned if STATUS_OK.

+Transmits a Wake-UP command, Type A. Invites PICCs in state IDLE and HALT to go to READY(*) and prepare for anticollision or selection. 7 bit frame.
Beware: When two PICCs are in the field at the same time I often get STATUS_TIMEOUT -probably due do bad antenna design.
return STATUS_OK on success, STATUS_??? otherwise.
byte MFRC522::PICC_WakeupA(
byte *bufferATQA, The buffer to store the ATQA (Answer to request) in
byte *bufferSize Buffer size, at least two bytes. Also number of bytes returned if STATUS_OK.

+Transmits SELECT/ANTICOLLISION commands to select a single PICC.
Before calling this function the PICCs must be placed in the READY(*) state by calling PICC_RequestA() or PICC_WakeupA().
On success:

-The chosen PICC is in state ACTIVE(*) and all other PICCs have returned to state IDLE/HALT. (Figure 7 of the ISO/IEC 14443-3 draft.)
-The UID size and value of the chosen PICC is returned in *uid along with the SAK.

A PICC UID consists of 4, 7 or 10 bytes.
Only 4 bytes can be specified in a SELECT command, so for the longer UIDs two or three iterations are used:
UID size | Number of UID bytes | Cascade levels | Example of PICC
======== | =================== | ============== | ===============
single | 4 | 1 | MIFARE Classic
double | 7 | 2 | MIFARE Ultralight
triple | 10 | 3 | Not currently in use?

return STATUS_OK on success, STATUS_??? otherwise.
byte MFRC522::PICC_Select(
Uid *uid, | Pointer to Uid struct. Normally output, but can also
be used to supply a known UID.
byte validBits | The number of known UID bits supplied in *uid.

Normally 0. If set you must also supply uid->size.

Description of buffer structure:

Byte 0: SEL | Indicates the Cascade Level: PICC_CMD_SEL_CL1,
PICC_CMD_SEL_CL2 or PICC_CMD_SEL_CL3
Byte 1: NVB | Number of Valid Bits (in complete command, not just the UID):
High nibble: complete bytes, Low nibble: Extra bits.
Byte 2: UID-data or CT See explanation below. CT means Cascade Tag.
Byte 3: UID-data
Byte 4: UID-data
Byte 5: UID-data
Byte 6: BCC | Block Check Character - XOR of bytes 2-5
Byte 7: CRC_A
Byte 8: CRC_A

The BCC and CRC_A is only transmitted if we know all the UID bits of the current Cascade Level.
Description of bytes 2-5: (Section 6.5.4 of the ISO/IEC 14443-3 draft: UID contents and cascade levels)
UID size | Cascade level | Byte2 Byte3 Byte4 Byte5
======== | ============= | ===== ===== ===== =====
4 bytes | 1 | uid0 uid1 uid2 uid3

7 bytes | 1 | CT | uid0 uid1 uid2
2 | uid3 uid4 uid5 uid6
10 bytes | 1 | CT | uid0 uid1 uid2
| 2 | CT | uid3 uid4 uid5

+Instructs a PICC in state ACTIVE(*) to go to state HALT. return STATUS_OK on success, STATUS_??? otherwise.
byte PICC_HaltA();
Example:
// Halt PICC
mfrc522.PICC_HaltA();

+Executes the MFRC522 MFAuthent command.
This command manages MIFARE authentication to enable a secure communication to any MIFARE Mini, MIFARE 1K and MIFARE 4K card.
The authentication is described in the MFRC522 datasheet section 10.3.1.9 and http://www.nxp.com/documents/data_sheet/MF1S503x.pdf section 10.1. for use with MIFARE Classic PICCs.
The PICC must be selected - ie in state ACTIVE(*) - before calling this function. Remember to call PCD_StopCrypto1() at the end of communication with the authenticated PICC - otherwise no new communications can start.
All keys are set to FFFFFFFFFFFFh at chip delivery.
return STATUS_OK on success, STATUS_??? otherwise. Probably STATUS_TIMEOUT if you supply the wrong key.
byte MFRC522::PCD_AuthenticateI(
byte command, | PICC_CMD_MF_AUTH_KEY_A or PICC_CMD_MF_AUTH_KEY_B
byte blockAddr, | The block number. See numbering in the comments in
| the .h file.
MIFARE_Key *key, | Pointer to the Crypto1 key to use (6 bytes)
Uid *uid | Pointer to Uid struct. The first 4 bytes of the UID
| is used.
)
Example:
MFRC522::MIFARE_Key key;
for (byte i = 0; i < 6; i++) key.keyByte[i] = 0xFF; byte trailerBlock = 7;
byte status;
if ( ! mfrc522.PICC_ReadCardSerial()) return;
status = mfrc522.PCD_Authenticate(MFRC522::PICC_CMD_MF_AUTH_KEY_A, trailerBlock, &key, &(mfrc522.uid));
if (status != MFRC522::STATUS_OK) {
Serial.print("PCD_Authenticate() failed: "); Serial.println(mfrc522.GetStatusCodeName(status)); return;
}

+Used to exit the PCD from its authenticated state.
Remember to call PCD_StopCrypto1() at the end of communication with the authenticated PICC - otherwise no new communications can start.
void MFRC522::PCD_StopCrypto1()
Example:
// Stop encryption on PCD
mfrc522.PCD_StopCrypto1();

+Reads 16 bytes (+ 2 bytes CRC_A) from the active PICC.
For MIFARE Classic the sector containing the block must be authenticated before calling this function.
For MIFARE Ultralight only addresses 00h to 0Fh are decoded.
* The MF0ICU1 returns a NAK for higher addresses.

* The MF0ICU1 responds to the READ command by sending 16 bytes starting from
the page address defined by the command argument.
* For example; if blockAddr is 03h then pages 03h, 04h, 05h, 06h are returned.
* A roll-back is implemented: If blockAddr is 0Eh, then the contents of pages 0Eh, 0Fh, 00h and 01h are returned.
The buffer must be at least 18 bytes because a CRC_A is also returned.
Checks the CRC_A before returning STATUS_OK.
return STATUS_OK on success, STATUS_??? otherwise.
byte MFRC522::MIFARE_Read(
byte blockAddr, | MIFARE Classic: The block (0-0xff) number.
| MIFARE Ultralight: The first page to return data from.
byte *buffer, | The buffer to store the data in

byte *bufferSize Buffer size, at least 18 bytes. Also number of bytes returned
| if STATUS_OK.
Example:
byte valueBlockA = 4; byte buffer[18]; byte size = sizeof(buffer);
byte status = mfrc522.MIFARE_Read(valueBlockA, buffer, &size);

+Writes 16 bytes to the active PICC.
For MIFARE Classic the sector containing the block must be authenticated before calling this function.
For MIFARE Ultralight the operation is called "COMPATIBILITY WRITE".
Even though 16 bytes are transferred to the Ultralight PICC, only the least significant 4 bytes (bytes 0 to 3) are written to the specified address. It is recommended to set the remaining bytes 04h to 0Fh to all logic 0.
return STATUS_OK on success, STATUS_??? otherwise.
byte MFRC522::MIFARE_Write(
byte blockAddr,
| MIFARE Classic: The block (0-0xff) number.
| MIFARE Ultralight: The page (2-15) to write to.
byte *buffer, | The 16 bytes to write to the PICC
byte bufferSize | Buffer size, must be at least 16 bytes. Exactly 16 bytes are
| written.
Example:
byte valueBlockA = 4;
byte value1Block[] = { 1,2,3,4, 5,6,7,8, 9,10,255,12, 13,14,15,16}; status = mfrc522.MIFARE_Write(valueBlockA, value1Block, 16);
if (status != MFRC522::STATUS_OK) {
Serial.print("MIFARE_Write() failed: "); Serial.println(mfrc522.GetStatusCodeName(status));
}

+MIFARE Decrement subtracts the delta from the value of the addressed block, and stores the result in a volatile memory.
For MIFARE Classic only. The sector containing the block must be authenticated before calling this function.
Only for blocks in "value block" mode, ie with access bits [C1 C2 C3] = [110] or [001].
Use MIFARE_Transfer() to store the result in a block.
return STATUS_OK on success, STATUS_??? otherwise.
byte MFRC522::MIFARE_Decrement(
byte blockAddr, | The block (0-0xff) number.
long delta | This number is subtracted from the value of block blockAddr.

+MIFARE Increment adds the delta to the value of the addressed block, and stores the result in a volatile memory.
For MIFARE Classic only. The sector containing the block must be authenticated before calling this function.
Only for blocks in "value block" mode, ie with access bits [C1 C2 C3] = [110] or

[001].
Use MIFARE_Transfer() to store the result in a block. return STATUS_OK on success, STATUS_??? otherwise.
byte MFRC522::MIFARE_Increment(
byte blockAddr, | The block (0-0xff) number.
long delta | This number is added to the value of block blockAddr.
Example:
// Add 1 to the value of valueBlockA and store the result in valueBlockA. byte valueBlockA = 5;
Serial.print("Adding 1 to value of block "); Serial.println(valueBlockA); byte status = mfrc522.MIFARE_Increment(valueBlockA, 1);
if (status != MFRC522::STATUS_OK) {
Serial.print("MIFARE_Increment() failed: "); Serial.println(mfrc522.GetStatusCodeName(status)); return;
}
status = mfrc522.MIFARE_Transfer(valueBlockA);
if (status != MFRC522::STATUS_OK) { Serial.print("MIFARE_Transfer() failed: "); Serial.println(mfrc522.GetStatusCodeName(status)); return;
}

+MIFARE Restore copies the value of the addressed block into a volatile memory.
For MIFARE Classic only. The sector containing the block must be authenticated before calling this function.
Only for blocks in "value block" mode, ie with access bits [C1 C2 C3] = [110] or [001].
Use MIFARE_Transfer() to store the result in a block.
return STATUS_OK on success, STATUS_??? otherwise.
byte MFRC522::MIFARE_Restore(
byte blockAddr The block (0-0xff) number.
The datasheet describes Restore as a two step operation, but does not explain what data to transfer in step 2.Doing only a single step does not work, so I chose to transfer 0L in step two.

+Helper function for the two-step MIFARE Classic protocol operations Decrement, Increment and Restore.
return STATUS_OK on success, STATUS_??? otherwise.
byte MFRC522::MIFARE_TwoStepHelper(
byte command, | The command to use
byte blockAddr, | The block (0-0xff) number.
long data | The data to transfer in step 2
)

+MIFARE Transfer writes the value stored in the volatile memory into one MIFARE Classic block.
For MIFARE Classic only. The sector containing the block must be authenticated before calling this function.
Only for blocks in "value block" mode, ie with access bits [C1 C2 C3] = [110] or [001].
return STATUS_OK on success, STATUS_??? otherwise.
byte MFRC522::MIFARE_Transfer(
byte blockAddr The block (0-0xff) number.

+Returns a string pointer to a status code name. const char *MFRC522::GetStatusCodeName(
byte code | One of the StatusCode enums.
code values | return values

STATUS_OK: | "Success."
STATUS_ERROR: | "Error in communication."
STATUS_COLLISION: | "Collision detected."
STATUS_TIMEOUT: | "Timeout in communication."
STATUS_NO_ROOM: | "A buffer is not big enough."
STATUS_INTERNAL_ERROR: "Internal error in the code. Should not happen."
STATUS_INVALID: | "Invalid argument."
STATUS_CRC_WRONG: | "The CRC_A does not match."
STATUS_MIFARE_NACK: | "A MIFARE PICC responded with NAK."
default: | "Unknown error"

Example:
Serial.println(mfrc522.GetStatusCodeName(status));

+Translates the SAK (Select Acknowledge) to a PICC type. return PICC_Type
byte MFRC522::PICC_GetType(
byte sak | The SAK byte returned from PICC_Select().
sak | return value
sak & 0x04 | PICC_TYPE_NOT_COMPLETE
0x09 | PICC_TYPE_MIFARE_MINI
0x08 | PICC_TYPE_MIFARE_1K
0x18 | PICC_TYPE_MIFARE_4K
0x00 | PICC_TYPE_MIFARE_UL
0x10 or 0x11 | PICC_TYPE_MIFARE_PLUS
0x01 | PICC_TYPE_TNP3XXX
sak & 0x20 | PICC_TYPE_ISO_14443_4
sak & 0x40 | PICC_TYPE_ISO_18092
else | PICC_TYPE_UNKNOWN

+Returns a string pointer to the PICC type name. const char *MFRC522::PICC_GetTypeName(
byte piccType | One of the PICC_Type enums.
piccType | return value
PICC_TYPE_ISO_14443_4 | "PICC compliant with ISO/IEC 14443-4"
PICC_TYPE_ISO_18092: | "PICC compliant with ISO/IEC 18092 (NFC)"
PICC_TYPE_MIFARE_MINI | "MIFARE Mini, 320 bytes"
PICC_TYPE_MIFARE_1K | "MIFARE 1KB"
PICC_TYPE_MIFARE_4K | "MIFARE 4KB"
PICC_TYPE_MIFARE_UL | "MIFARE Ultralight or Ultralight C"
PICC_TYPE_MIFARE_PLUS | "MIFARE Plus"
PICC_TYPE_TNP3XXX | "MIFARE TNP3XXX"
PICC_TYPE_NOT_COMPLETE "SAK indicates UID is not complete."
PICC_TYPE_UNKNOWN | "Unknown type”
Example:
Serial.println(mfrc522.PICC_GetTypeName(piccType));

+Dumps debug info about the selected PICC to Serial.
On success the PICC is halted after dumping the data.
For MIFARE Classic the factory default key of 0xFFFFFFFFFFFF is tried. void MFRC522::PICC_DumpToSerial(
Uid *uid Pointer to Uid struct returned from a successful PICC_Select(). Example:
mfrc522.PICC_DumpToSerial(&(mfrc522.uid));

+Dumps memory contents of a sector of a MIFARE Classic PICC.
Uses PCD_Authenticate(), MIFARE_Read() and PCD_StopCrypto1.

Always uses PICC_CMD_MF_AUTH_KEY_A because only Key A can always read the sector trailer access bits.
void MFRC522::PICC_DumpMifareClassicSectorToSerial(
Uid *uid, | Pointer to Uid struct returned from a successful PICC_Select()
MIFARE_Key *key, Key A for the sector.
byte sector | The sector to dump, 0..39.

+Calculates the bit pattern needed for the specified access bits. In the [C1 C2 C3] tuples C1 is MSB (=4) and C3 is LSB (=1).
void MFRC522::MIFARE_SetAccessBits(
byte *accessBitBuffer, Pointer to byte 6, 7 and 8 in the sector trailer.
| Bytes [0..2] will be set.
byte g0, | Access bits [C1 C2 C3] for block 0 (for sectors 0-31) or blocks 0-4 (for sectors 32-39)
byte g1, | Access bits C1 C2 C3] for block 1 (for sectors 0-31) or blocks 5-9 (for sectors 32-39)
byte g2, | Access bits C1 C2 C3] for block 2 (for sectors 0-31) or blocks 10-14 (for sectors 32-39)
byte g3 | Access bits C1 C2 C3] for the sector trailer, block 3 (for sectors 0-31) or block 15 (for sectors 32-39)

The access bits are stored in a peculiar fashion.
There are four groups:

g[3] Access bits for the sector trailer, block 3 (for sectors 0-31) or block 15 (for sectors 32-39)

g[2] Access bits for block 2 (for sectors 0-31) or blocks 10-14 (for sectors 32-39) g[1] Access bits for block 1 (for sectors 0-31) or blocks 5-9 (for sectors 32-39) g[0] Access bits for block 0 (for sectors 0-31) or blocks 0-4 (for sectors 32-39)

Each group has access bits [C1 C2 C3]. In this code C1 is MSB and C3 is LSB.
The four CX bits are stored together in a nibble cx and an inverted nibble cx_. Example:
// Sector trailer that defines blocks 5 and 6 as Value Blocks and enables key B. byte trailerBuffer[] = {255,255,255,255,255,255,0,0,0,0, 255,255,255,255,255,255}; // Keep default keys.
// g1=6(i.e.110) => block 5 value block. Key B write&increment, A or B decrement. // g2=6 => Same thing for block 6.
// g3=3 => Key B must be used to modify the Sector Trailer. Key B becomes valid. mfrc522.MIFARE_SetAccessBits(&trailerBuffer[6], 0, 6, 6, 3);

+Check if a card is present
bool MFRC522::PICC_IsNewCardPresent()
Returns true if a PICC responds to PICC_CMD_REQA.
Only "new" cards in state IDLE are invited. Sleeping cards in state HALT are ignored. Example:
// Look for new cards
if ( ! mfrc522.PICC_IsNewCardPresent()) return;

+Read Card Serial
bool MFRC522::PICC_ReadCardSerial()
Simple wrapper around PICC_Select.
Returns true if a UID could be read.The read UID is available in the class variable uid.
Remember to call PICC_IsNewCardPresent(), PICC_RequestA() or PICC_WakeupA() first. return true if one selected

Now a card is selected. The UID and SAK is in mfrc522.uid. Example:
Serial.print("Card UID:");
for (byte i = 0; i < mfrc522.uid.size; i++) { Serial.print(mfrc522.uid.uidByte[i] < 0x10 ? " 0" : " "); Serial.print(mfrc522.uid.uidByte[i], HEX);
}
// Dump PICC type
byte piccType = mfrc522.PICC_GetType(mfrc522.uid.sak); Serial.print("PICC type: "); Serial.println(mfrc522.PICC_GetTypeName(piccType));
if ( piccType != MFRC522::PICC_TYPE_MIFARE_MINI
&& piccType != MFRC522::PICC_TYPE_MIFARE_1K
&& | piccType != MFRC522::PICC_TYPE_MIFARE_4K) {
Serial.println("This sample only works with MIFARE Classic cards."); return;
}

How to convert a normal block into a value block
Usually a normal block has 000 access bits, while a value block has 110 access bits Example:
byte valueBlockA = 5;
byte valueBlockB = 6;
byte trailerBlock = 7;
// We need a sector trailer with blocks 5 and 6 as Value Blocks and enables key B. byte trailerBuffer[] = { 255,255,255,255,255,255,
| 0,0,0,0,255,255,255,255,255,255}; // Keep default keys.
// g1=6 => block 5 as value block. Key B to write&increment, A or B for decrement. // g2=6 => Same thing for block 6.
// g3=3 => Key B must be used to modify the Sector Trailer. Key B becomes valid. mfrc522.MIFARE_SetAccessBits(&trailerBuffer[6], 0, 6, 6, 3);
byte status = mfrc522.MIFARE_Write(trailerBlock, trailerBuffer, 16);
if (status != MFRC522::STATUS_OK) {
Serial.print("MIFARE_Write() failed: "); Serial.println(mfrc522.GetStatusCodeName(status));
return;
}

How to setup a Value Block with a value set to zero Example:
byte blockAddr=5;
byte valueBlock[] = {0,0,0,0, 255,255,255,255, 0,0,0,0,
| blockAddr,~blockAddr,blockAddr,~blockAddr };
byte status = mfrc522.MIFARE_Write(blockAddr, valueBlock, 16); if (status != MFRC522::STATUS_OK) { Serial.print("MIFARE_Write() failed: "); Serial.println(mfrc522.GetStatusCodeName(status));
}

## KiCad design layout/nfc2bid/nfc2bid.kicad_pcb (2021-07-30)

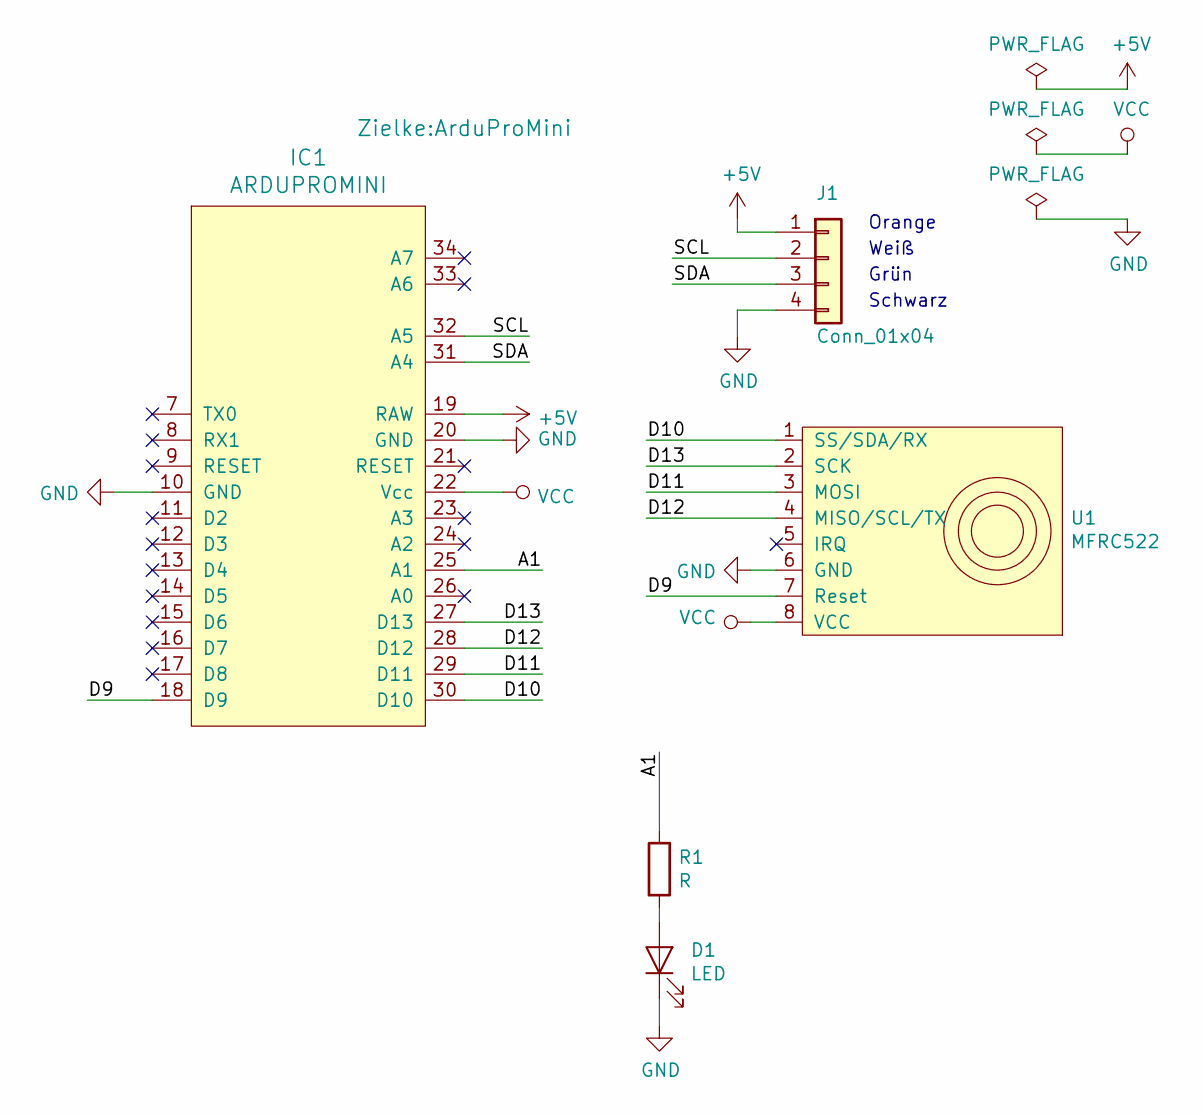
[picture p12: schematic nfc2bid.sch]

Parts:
D1: LED; LED_D3.0mm_Clear
IC1: ARDUPROMINI; ArduProMini
J1: Conn_01x04; PinHeader_1x04_P2.54mm_Horizontal
R1: R; R_Axial_DIN0309_L9.0mm_D3.2mm_P12.70mm_Horizontal
U1: MFRC522

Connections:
+5V: IC1.19 (RAW), J1.1
/A1: IC1.25 (A1), R1.1
/D9: IC1.18 (D9), U1.7 (Reset)
/D10: IC1.30 (D10), U1.1 (SS/SDA/RX)
/D11: IC1.29 (D11), U1.3 (MOSI)
/D12: IC1.28 (D12), U1.4 (MISO/SCL/TX)
/D13: IC1.27 (D13), U1.2 (SCK)
/SCL: IC1.32 (A5), J1.2
/SDA: IC1.31 (A4), J1.3
GND: D1.1 (K), IC1.10 (GND), IC1.20 (GND), J1.4, U1.6 (GND)
unnamed: D1.2 (A), R1.2
VCC: IC1.22 (Vcc), U1.8 (VCC)

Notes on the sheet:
Orange
Weiß
Grün
Schwarz

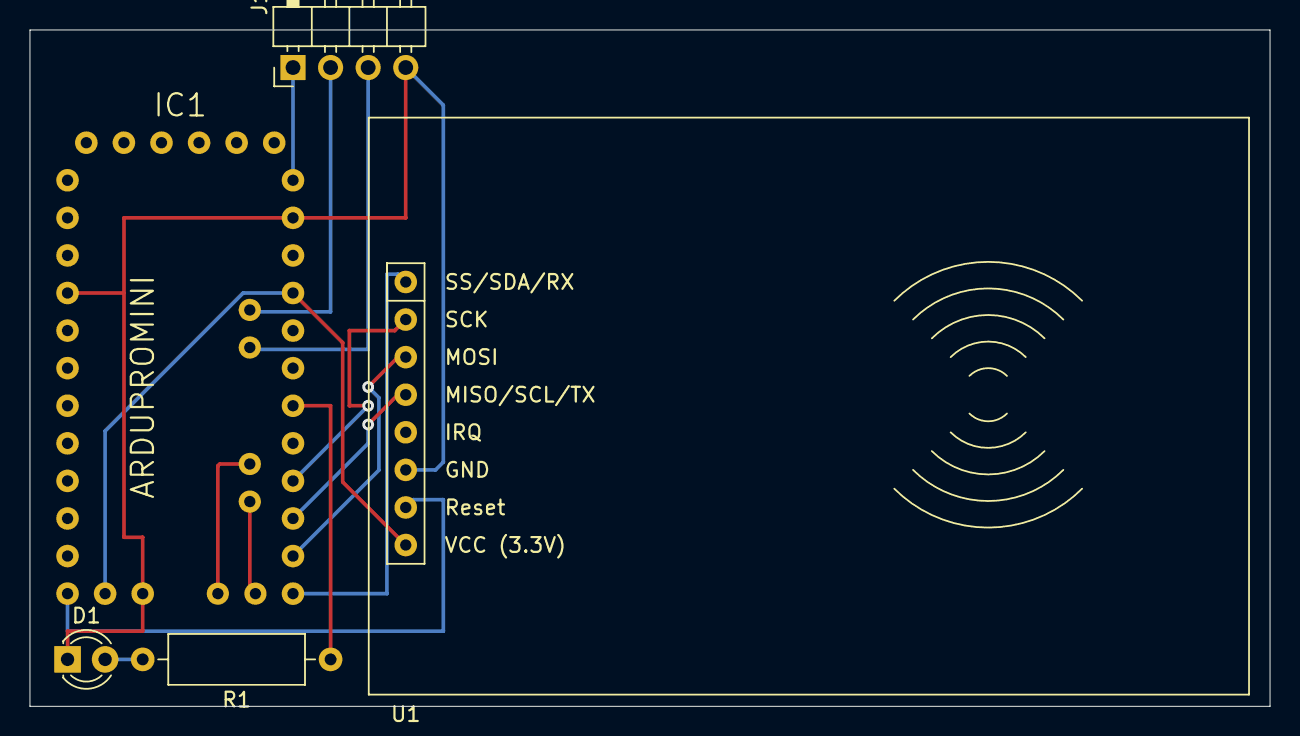
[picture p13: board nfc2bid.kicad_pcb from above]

Board: 2 copper layers, 83.8 x 45.7 mm, 5 parts (0 on the bottom side), 12 nets.

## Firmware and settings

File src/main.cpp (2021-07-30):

#include <Arduino.h>
#include <Wire.h>

#include "global.h"

// Setup RFID CHIP
#include <deprecated.h>
#include <MFRC522.h>
#include <MFRC522Extended.h>
#include <require_cpp11.h>

/**
 * Verlauf 
 * 29.8.16  Status LED als Konstante, NFC Gain im Main code
 * 
 * 
 * 
 * ----------------------------------------------------------------------------
 *  MFRC522 library  https://github.com/miguelbalboa/rfid
 * 
 * Projekt zu lesen im RCN Microcotroller Bereich
 * 
 * Benötigte Lesechips Miface Classic 1K
 * 
 * 
 * WICHTIGE INFOS !!!!!!
 * WIRD ein BIDCHIP(NFC) mit Jahr 2100 abgelegt kann damit der Chip Entfernt werden!!!!
 * 
 * 
 * ----------------------------------------------------------------------------
 * 
 * Verbindung Arduino /// NFC Leser :
 * -----------------------------------
 *             MFRC522      Arduino    
 *             Reader/PCD   Uno / Nano         
 * Signal      Pin          Pin          
 * ----------------------------------
 * RST/Reset   RST          9          
 * SPI SS      SDA(SS)      10      
 * SPI MOSI    MOSI         11
 * SPI MISO    MISO         12 
 * SPI SCK     SCK          13  
 * 
 * 
 * 
 * Verbindung Arduino /// BID Port :
 * -----------------------------------
 *            Robbe Lader     Arduino    
 *             BID            Uno / Nano         
 * Signal      Kabel          Pin          
 * ----------------------------------
 * Masse       Schwarz         GND         
 * SCL         Weiss           5      
 * SDA         Gruen           4

 * 
 */

#define SS_PIN 10  //slave select pin
#define RST_PIN 9  //reset pin

MFRC522 mfrc522(SS_PIN, RST_PIN);        
MFRC522::MIFARE_Key key;

// Frei Einstellbare Parameter
const int status_led_1_Pin = A1;  // Pin fuer Status LED
int BID_Reconnect_time = 3000;  // Zeit wie lange Pause BEI Bidwechsel ist, bei fehler erhöhen
int I2C_Adresse_BID_Chip = 80;   //Adresse des BID Chips
const int I2C_Adresse_BID_no_Chip = 89;  //Dummy adresse um den BUS zu sperren
#define PCD_RxGain RxGain_max

//Setup ROBBE BID Chip
int t = 0;
byte adresse =0;
int dat=0;
byte last_byte = 0;
int counter =0;
bool err =0;
byte BID_NFC[256];
byte BID_aktiv[256];
bool bid_daten_NFC_syncron =0;


int block=2;
byte blockcontent[16] =  {"               "};
byte Chip_serial[16] =   {"               "};
byte aktiver_Chip_serial[16] =   {"               "};
int chip_status =0;
bool _bid_aktiv = false;
bool daten_syncron = true;
bool Chip_wechsel = true;
bool lesefehler = false;
//byte blockcontent[16] = {0,0,0,0,0,0,0,0,0,0,0,0,0,0,0,0};//all zeros. This can be used to delete a block.
byte readbackblock[18];//This array is used for reading out a block. The MIFARE_Read method requires a buffer that is at least 18 bytes to hold the 16 bytes of a block.

#pragma pack(push, 1)
typedef struct {
  uint16_t  checksum;         // [0..1]  Checksum, sum up bytes from 2..127
  uint16_t  act_charge;       // [2..3]
  uint16_t  max_charged;      // [4..5]
  uint16_t  chg_cycles;       // [6..7]
  uint8_t   unknown_8[63-7];  // [8..63]
  uint8_t   year;             // [64]
  uint8_t   month;            // [65]
  uint8_t   day;              // [66]
  uint8_t   acctyp;           // [67]
  uint8_t   cells;            // [68]
  uint16_t  capacity;         // [69..70]
  uint16_t  chg_current;      // [71..72]
  uint16_t  dischg_current;   // [73..74]
  uint16_t  dischg_limit;     // [75..76] discharge limit in mv/Cell
  uint8_t   d_peak;           // [77] delta peak value
  uint8_t   cut_temp;         // [78] cut off temperature
  uint8_t   unknown;
  uint8_t   unknown75[128-80];
}tBID_data;
#pragma pack(pop)

//#################################################
// funktions
//#################################################
void endianSwap(uint16_t* w)
{
  *w = (((*w>>8) & 0x00ff) | ((*w & 0x00ff)<<8));
}

void printByteHex(uint8_t b)
{
  char buffer[4];
  sprintf(buffer, "%02x", b); 
  Serial.print(buffer);
}

void print_BID_Data()
{
  Serial.println("Print BID Data");

  //HEX-Dump
  int i = 0;
  while(i<256)
  {
    printByteHex(i);  // Address
    Serial.print(":");
    
    int j = 0;
    while(j < 16)
    {
      Serial.print(" ");
      printByteHex(BID_NFC[i]);
      j++;
      i++;
    }
    Serial.println();
  }

  //Print Data
  tBID_data bidData;
  memcpy(&bidData,&BID_NFC,sizeof(bidData));
  endianSwap(&bidData.checksum);
  endianSwap(&bidData.act_charge);
  endianSwap(&bidData.max_charged);
  endianSwap(&bidData.chg_cycles);
  endianSwap(&bidData.capacity);
  endianSwap(&bidData.chg_current);
  endianSwap(&bidData.dischg_current);
  endianSwap(&bidData.dischg_limit);
  Serial.print("Checksum:       "); Serial.println(bidData.checksum);
  Serial.print("act_charge:     "); Serial.println(bidData.act_charge);
  Serial.print("max_charged:    "); Serial.println(bidData.max_charged);
  Serial.print("chg_cycles:     "); Serial.println(bidData.chg_cycles);
  Serial.print("year:           "); Serial.println(bidData.year);
  Serial.print("month:          "); Serial.println(bidData.month);
  Serial.print("day:            "); Serial.println(bidData.day);
  Serial.print("acctyp:         "); Serial.println(bidData.acctyp);
  Serial.print("cells:          "); Serial.println(bidData.cells);
  Serial.print("capacity:       "); Serial.println(bidData.capacity);
  Serial.print("chg_current:    "); Serial.println(bidData.chg_current);
  Serial.print("dischg_current: "); Serial.println(bidData.dischg_current);
  Serial.print("dischg_limit:   "); Serial.println(bidData.dischg_limit);
  Serial.print("d_peak:         "); Serial.println(bidData.d_peak);
  Serial.print("cut_temp:       "); Serial.println(bidData.cut_temp);
  Serial.print("unknown:        "); Serial.println(bidData.unknown);
  Serial.print("unknown_8[0]:   "); Serial.println(bidData.unknown_8[0]);
  Serial.print("unknown_8[1]:   "); Serial.println(bidData.unknown_8[1]);
  Serial.print("unknown_8[2]:   "); Serial.println(bidData.unknown_8[2]);
  Serial.print("unknown_8[3]:   "); Serial.println(bidData.unknown_8[3]);
  Serial.print("unknown_8[4]:   "); Serial.println(bidData.unknown_8[4]);
  Serial.print("unknown_8[5]:   "); Serial.println(bidData.unknown_8[5]);
  Serial.print("unknown_8[6]:   "); Serial.println(bidData.unknown_8[6]);
  Serial.print("unknown_8[7]:   "); Serial.println(bidData.unknown_8[7]);
}

// function that executes whenever data is received from master
// this function is registered as an event, see setup()
void receiveEvent(int howMany) {
  //Serial.print("EE");
  t=0;
  while (1 < Wire.available()) { // loop through all but the last
    t++;
    Serial.println("loop");
    adresse = Wire.read(); // receive byte as a character       // print the character
    //Serial.println(adresse); 
    dat=1;
  }
  byte x = Wire.read();    // receive byte as an integer
  last_byte = x;
  ///Serial.println("last_byte");
  //Serial.println(last_byte);         // print the integer
  if (t==1){
    dat=0;
    daten_syncron = false;
    BID_aktiv[adresse]=last_byte;

    //DEBUG EEPROM Schreiben    
    //Serial.print("write to ");
    //Serial.print(adresse);
    //Serial.print("  ");
    //Serial.println(last_byte);
  }
}

void requestEvent() 
{
  //Serial.print("Request from Master. Sending: ");
  //Serial.print(x, HEX);
  //Serial.print("\n");
  //Serial.print("read adrr ");
  //Serial.print(last_byte);
  //Serial.print(" ");
  //Serial.println(BID_aktiv[last_byte]);
  Wire.write(BID_aktiv[last_byte]);
}

int writeBlock(int blockNumber, byte arrayAddress[]) 
{
  //this makes sure that we only write into data blocks. Every 4th block is a trailer block for the access/security info.
  int largestModulo4Number=blockNumber/4*4;
  int trailerBlock=largestModulo4Number+3;//determine trailer block for the sector
  if (blockNumber > 2 && (blockNumber+1)%4 == 0){Serial.print(blockNumber);Serial.println(" is a trailer block:");return 2;}//block number is a trailer block (modulo 4); quit and send error code 2
  Serial.print(blockNumber);
  Serial.println(" is a data block:");
  
  /*****************************************authentication of the desired block for access***********************************************************/
  byte status = mfrc522.PCD_Authenticate(MFRC522::PICC_CMD_MF_AUTH_KEY_A, trailerBlock, &key, &(mfrc522.uid));
  //byte PCD_Authenticate(byte command, byte blockAddr, MIFARE_Key *key, Uid *uid);
  //this method is used to authenticate a certain block for writing or reading
  //command: See enumerations above -> PICC_CMD_MF_AUTH_KEY_A  = 0x60 (=1100000),    // this command performs authentication with Key A
  //blockAddr is the number of the block from 0 to 15.
  //MIFARE_Key *key is a pointer to the MIFARE_Key struct defined above, this struct needs to be defined for each block. New cards have all A/B= FF FF FF FF FF FF
  //Uid *uid is a pointer to the UID struct that contains the user ID of the card.
  if (status != MFRC522::STATUS_OK) {
         Serial.print("PCD_Authenticate() failed: ");
         //Serial.println(mfrc522.GetStatusCodeName(status));
         return 3;//return "3" as error message
  }
  //it appears the authentication needs to be made before every block read/write within a specific sector.
  //If a different sector is being authenticated access to the previous one is lost.


  /*****************************************writing the block***********************************************************/
        
  status = mfrc522.MIFARE_Write(blockNumber, arrayAddress, 16);//valueBlockA is the block number, MIFARE_Write(block number (0-15), byte array containing 16 values, number of bytes in block (=16))
  //status = mfrc522.MIFARE_Write(9, value1Block, 16);
  if (status != MFRC522::STATUS_OK) {
           Serial.print("MIFARE_Write() failed: ");
           //Serial.println(mfrc522.GetStatusCodeName(status));
           err =1;
           return 4;//return "4" as error message
  }
  Serial.println("block was written");
  return 0;
}

int readBlock(int blockNumber, byte arrayAddress[]) 
{
  int largestModulo4Number=blockNumber/4*4;
  int trailerBlock=largestModulo4Number+3;//determine trailer block for the sector

  /*****************************************authentication of the desired block for access***********************************************************/
  byte status = mfrc522.PCD_Authenticate(MFRC522::PICC_CMD_MF_AUTH_KEY_A, trailerBlock, &key, &(mfrc522.uid));
  //byte PCD_Authenticate(byte command, byte blockAddr, MIFARE_Key *key, Uid *uid);
  //this method is used to authenticate a certain block for writing or reading
  //command: See enumerations above -> PICC_CMD_MF_AUTH_KEY_A = 0x60 (=1100000),    // this command performs authentication with Key A
  //blockAddr is the number of the block from 0 to 15.
  //MIFARE_Key *key is a pointer to the MIFARE_Key struct defined above, this struct needs to be defined for each block. New cards have all A/B= FF FF FF FF FF FF
  //Uid *uid is a pointer to the UID struct that contains the user ID of the card.
  if (status != MFRC522::STATUS_OK) {
         Serial.print("PCD_Authenticate() failed (read): ");
         err =1;
         //Serial.println(mfrc522.GetStatusCodeName(status));
         return 3;//return "3" as error message
  }
  //it appears the authentication needs to be made before every block read/write within a specific sector.
  //If a different sector is being authenticated access to the previous one is lost.


  /*****************************************reading a block***********************************************************/
        
  byte buffersize = 18;//we need to define a variable with the read buffer size, since the MIFARE_Read method below needs a pointer to the variable that contains the size... 
  status = mfrc522.MIFARE_Read(blockNumber, arrayAddress, &buffersize);//&buffersize is a pointer to the buffersize variable; MIFARE_Read requires a pointer instead of just a number
  if (status != MFRC522::STATUS_OK) {
          Serial.print("MIFARE_read() failed: ");
          //Serial.println(mfrc522.GetStatusCodeName(status));
          err =1;
          return 4;//return "4" as error message
  }
  Serial.println("block was read");
  return 0;
}

/***************************************** Lese / Schreibroutinen NFC // I2C **********************************************************************/

void Write_from_Ram_to_NFC()
{
  block=2;
  counter =0;
  for (int z=0 ; z<16 ; z++)
  {
    for (int j=0 ; j<16 ; j++)//print the block content
    {
      digitalWrite(status_led_1_Pin, !digitalRead(status_led_1_Pin));
      blockcontent[j] = BID_aktiv[counter];
      //Serial.print("Block:");
      //Serial.print(block);
      //Serial.print(" byte no:");
      //Serial.print(j);
      //Serial.print(" BID Byte");
      //Serial.print(counter);
      //Serial.print(" Inhalt:");
      //Serial.println(blockcontent[j],HEX);
      counter++;
    }
    writeBlock(block, blockcontent);//the blockcontent array is written into the card block
    block++;
    if (block==3) {
      block++;
    }
    if (block==7) {
      block++;
    }

    if (block==11) {
    block++;
    }

    if (block==15) {
      block++;
    }

    if (block==19) {
      block++;
    }           
    if (block==23) {
      block++;
    }           
  }

  Serial.println("");
  digitalWrite(status_led_1_Pin, HIGH);
}

void read_from_NFC_to_RAM()
{
  Serial.print("Start lesen");
  block=2;
  counter =0;
  for (int z=0 ; z<16 ; z++)
  {
    readBlock(block, readbackblock);
    digitalWrite(status_led_1_Pin, !digitalRead(status_led_1_Pin));
    for (int j=0 ; j<16 ; j++)//print the block contents
    {
      //Serial.print("Block:");
      //Serial.print(block);
      //Serial.print(" byte no:");
      //Serial.print(j);
      //Serial.print(" BID Byte");
      //Serial.print(counter);
      //Serial.print(" Inhalt:");
      //Serial.println(readbackblock[j],HEX);

      BID_NFC[counter]=readbackblock[j];
      counter++;
    // Serial.print (readbackblock[j],HEX);//Serial.write() transmits the ASCII numbers as human readable characters to serial monitor
    }
    block++;
    if (block==3) {
      block++;
    }
    if (block==7) {
      block++;
    }

    if (block==11) {
      block++;
    }

    if (block==15) {
      block++;
    }
    if (block==19) {
      block++;
    }           
    if (block==23) {
      block++;
    }           
  }
  Serial.print("ende lesen");
  Serial.println("");
  
  print_BID_Data();
  
  digitalWrite(status_led_1_Pin, HIGH);
}

//#################################################

void setup() {
  pinMode(status_led_1_Pin, OUTPUT); 
  Serial.begin(115200);      // Initialize serial communications with the PC
  Serial.println(VERSION);

  SPI.begin();               // Init SPI bus
  mfrc522.PCD_Init();        // Init MFRC522 card (in case you wonder what PCD means: proximity coupling device)
  Serial.println("Scan a MIFARE Classic card");
  

  for (byte i = 0; i < 6; i++) {
    key.keyByte[i] = 0xFF;//keyByte is defined in the "MIFARE_Key" 'struct' definition in the .h file of the library
  }
  // I2c BID
  //Wire.begin(80);                // join i2c bus with address #80
  Wire.onReceive(receiveEvent); // register event
  Wire.onRequest(requestEvent);
  //Serial.print(BID[1]);

  //digitalWrite(2, LOW);
}

void loop()
{
  if (lesefehler == true){
    delay(10);
    Serial.println(" read err loop");
    digitalWrite(status_led_1_Pin, !digitalRead(status_led_1_Pin));
  }
  else
  {
    delay(400);
    if (daten_syncron == false)
    {
      Serial.println("loop");
      Serial.println("Syncronisieren noetig");
      digitalWrite(status_led_1_Pin, !digitalRead(status_led_1_Pin));
    }
  }
  //digitalWrite(status_led_1_Pin, HIGH);

  /***************************************** contact with a tag/card**********************************************************************/
  mfrc522.PCD_Init();      
  
  // Look for new cards (in case you wonder what PICC means: proximity integrated circuit card)
  if ( ! mfrc522.PICC_IsNewCardPresent()) //if PICC_IsNewCardPresent returns 1, a new card has been found and we continue
  {
    return;//if it did not find a new card is returns a '0' and we return to the start of the loop
  }
  
  // Select one of the cards
  if ( ! mfrc522.PICC_ReadCardSerial()) //if PICC_ReadCardSerial returns 1, the "uid" struct 
  {
    return; //if it returns a '0' something went wrong and we return to the start of the loop
  }

  
  Serial.println("Chip gefunden!");

  /*****************************************Auslesen der Seriennummer **********************************************************************/
  block=0;
  err =0;
  Serial.print("Lese Seriennummer aus :");
  readBlock(block, Chip_serial);//read the block back
  if (err==1)
  {
    Serial.println("Error reading Chip Serial");
    return; 
  }
    
  for (int j=0 ; j<16 ; j++) //print the block contents
  {
    Serial.print (Chip_serial[j],HEX);//Serial.write() transmits the ASCII numbers as human readable characters to serial monitor
  }
  Serial.println("");        

  /***************************************** Erster BID Bei Programmstart  **********************************************************************/ 
  
  // Fuer Programmstart erste Verbindung zum bid  -- NFC
  if (_bid_aktiv == false)
  {
    err=0;
    
    for (int z=0 ; z<16 ; z++)
    {
      aktiver_Chip_serial[z]=Chip_serial[z];
    }
  
    read_from_NFC_to_RAM();
  
    for (int z=0 ; z<256 ; z++)
    {
      BID_aktiv[z]=BID_NFC[z];
    }   

    Serial.println("read errors:");  
    Serial.println(err);       
    if (err == 1)
    {
      lesefehler = true;  
    }
    else
    {    
      Wire.begin(I2C_Adresse_BID_Chip);
      daten_syncron = true;
      Chip_wechsel = false;
      lesefehler = false;
      _bid_aktiv = true;
      digitalWrite(status_led_1_Pin, HIGH);
    }
  }
  
  /*****************************************Abgleich ob ein Chip mit anderer Seriennumer gesteckt wurde **********************************************************************/ 
  // Abgleich ob ein Chip mit anderer Seriennumer gesteckt wurde
  Chip_wechsel = false;
  for (int z=0 ; z<16 ; z++)
  {
    if (aktiver_Chip_serial[z] != Chip_serial[z])
    {
      Chip_wechsel = true;
      Serial.println(aktiver_Chip_serial[z]);
      Serial.println(" ");
      Serial.println(Chip_serial[z]);
      Serial.println("Chip wechsel");
    }
  }

  /***************************************** Bei ungleichheit NFC / Ram daten Auf NFC Sichen **********************************************************************/
  if (daten_syncron == false && Chip_wechsel == false && _bid_aktiv == true)
  {
    err=0;
    Write_from_Ram_to_NFC();
    //read_from_NFC_to_RAM();
   
    Serial.println("daten syncronisiert");
    digitalWrite(status_led_1_Pin, HIGH);
    if (err==0)
    {    
      daten_syncron = true;
    }   
  }

  /***************************************** Neuen Chip nicht annehmen solange noch ungesicherte daten da sind **********************************************************************/
  if (daten_syncron == false && Chip_wechsel == true && _bid_aktiv == true)
  {
    Serial.println("Daten Nicht Syncron !!! Kein Chipwechsel");
  }

  /***************************************** Chipwechsel wenn alle daten gesichert **********************************************************************/  
  if (daten_syncron == true && Chip_wechsel == true && _bid_aktiv == true)
  {
    Serial.println("led low");
    
    Wire.begin(I2C_Adresse_BID_no_Chip);

    err=0;     
    read_from_NFC_to_RAM();
    
    digitalWrite(status_led_1_Pin, LOW);
    for (int z=0 ; z<256 ; z++)
    {
      BID_aktiv[z]=BID_NFC[z];
    }

    lesefehler = true;           
    delay(BID_Reconnect_time);
    //Serial.println("Chip Gewechselt");
    if (err==0)
    { 
      // Copy versetzt
      for (int z=0 ; z<16 ; z++)
      {
        aktiver_Chip_serial[z]=Chip_serial[z];
      }       
      Wire.begin(I2C_Adresse_BID_Chip);
      lesefehler = false;
      daten_syncron = true;
      Chip_wechsel = false;    
      Serial.println("Chip Gewechselt");
      if (BID_NFC[64] == 100)
      {
        Serial.println("Jahreszahl 2100 erkannt");
        Wire.begin(I2C_Adresse_BID_no_Chip);
        _bid_aktiv = false;
        daten_syncron = true;
        Chip_wechsel = true;
        delay(5000);  
      }
    } 

    if (_bid_aktiv == true)
    {
      digitalWrite(status_led_1_Pin, HIGH);
    }
  } 
}

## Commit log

2021-07-29 Initial checkin Layout
    [nfc2bid.kicad_pcb, nfc2bid.sch]
2021-07-29 Refactoring für ProMini 3,3V 8MHz
2021-07-29 global.h erzeugt und Version eingefügt
2021-07-29 Print Version beim Start
2021-07-29 Kicad ProMini
    [nfc2bid.sch]
2021-07-29 Fix zweite Karte lesen
    [main.cpp]
2021-07-29 Infos für die BID Speicherstruktur
